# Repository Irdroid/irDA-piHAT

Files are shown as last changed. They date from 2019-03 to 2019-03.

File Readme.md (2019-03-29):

# irDA piHAT Transceiver for Raspberry Pi

The IrDA piHAT is a IrDA SIR transceiver HAT for raspberry Pi. It will allow you to experiment and develop solutions that require IrDA SIR serial communication from 9600 to 115200 baud rates. The IrDA piHAT comes pre-configured for 9600 bps serial SIR communication with the target IR device.

- Complete solution for IrDA communication on Raspberry Pi
- Supports with IrDA® Physical Layer Specification (version 1.3)
- High quality infrared transceiver
- Up to *5 meters IrDA SIR communication
- Supports Baud rates from 9600 – 115200 bps
- No drivers are required

### Version
1.0
### Grab a sample

You can grab a sample board from https://irdroid.eu/product/irda-pihat/

### Todos

 - n/a
 
License
----
GPL 2.0

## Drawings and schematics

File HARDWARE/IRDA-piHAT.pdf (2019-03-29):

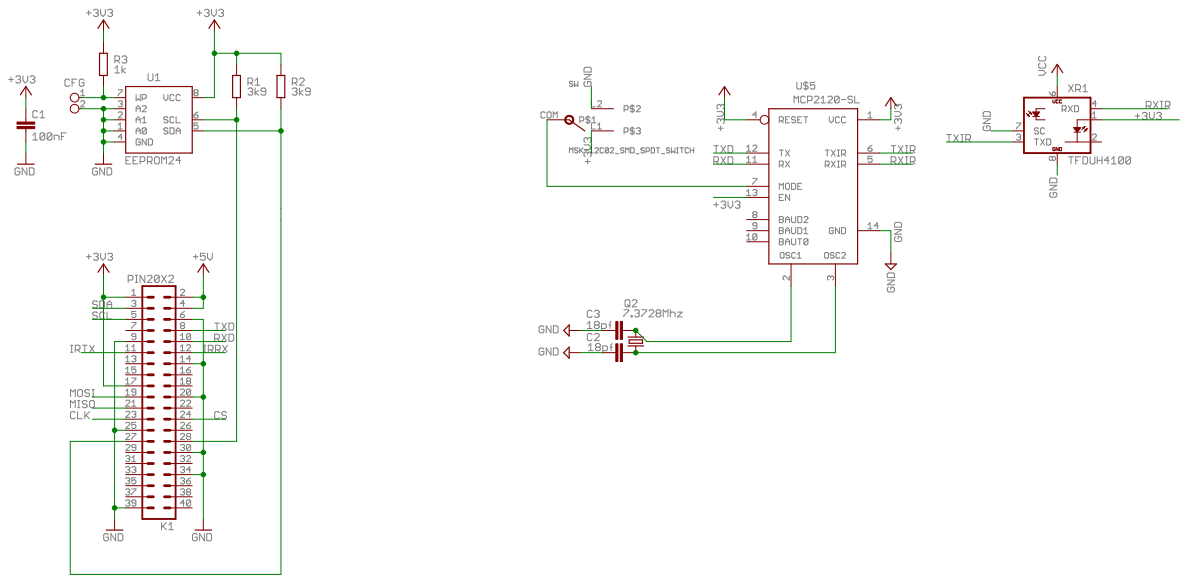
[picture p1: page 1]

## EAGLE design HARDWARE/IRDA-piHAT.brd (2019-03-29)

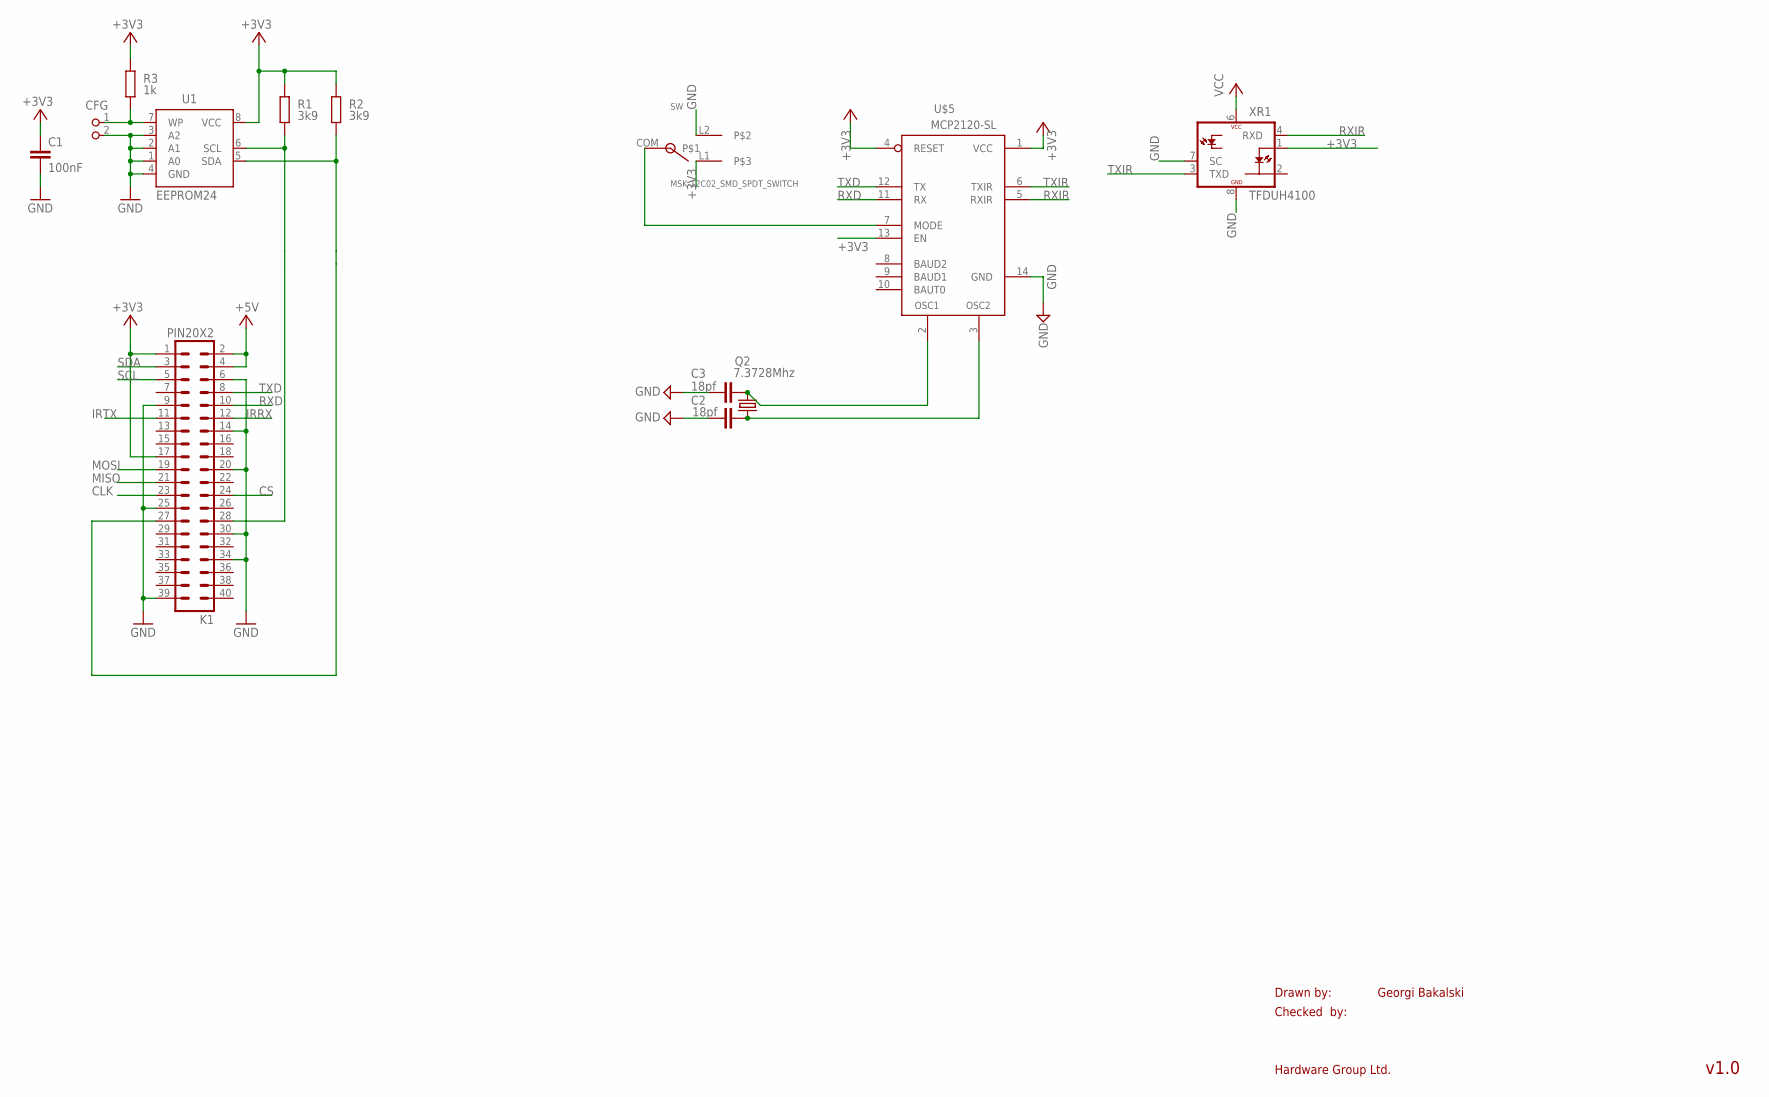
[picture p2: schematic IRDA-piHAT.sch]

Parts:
C1: 100nF; C0805K
C2, C3: 18pf; C603
CFG: PIN2_100; PIN_W_2
K1: PIN20X2; PIN_20X2
Q2: 7.3728Mhz; HC49UP
R1, R2: 3k9; M0805; TOLERANCE 5%
R3: 1k; M0805; TOLERANCE 5%
SW: MSK-12C02_SMD_SPDT_SWITCH; MSK-12C02
U1: EEPROM24; SOIC8
U$5: MCP2120-SL; SO-14
XR1: TFDUH4100; TFDU4-HOR

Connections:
+3V3: C1.1, K1.1, K1.17, R1.2, R2.2, R3.2, SW.L1, U1.8 (VCC), U$5.1 (VCC), U$5.4 (RESET), U$5.13 (EN), XR1.1 (IRED-A), XR1.6 (VCC)
+5V: K1.2, K1.4
CLK: K1.23
CS: K1.24
GND: C1.2, C2.2, C3.2, CFG.2, K1.6, K1.9, K1.14, K1.20, K1.25, K1.30, K1.34, K1.39, SW.L2, U1.1 (A0), U1.2 (A1), U1.3 (A2), U1.4 (GND), U$5.14 (GND), XR1.7 (SC), XR1.8 (GND)
IRRX: K1.12
IRTX: K1.11
MISO: K1.21
MOSI: K1.19
unnamed: CFG.1, R3.1, U1.7 (WP)
unnamed: C3.1, Q2.2, U$5.2 (OSC1)
unnamed: C2.1, Q2.1, U$5.3 (OSC2)
unnamed: SW.COM, U$5.7 (MODE)
unnamed: K1.28, R1.1, U1.6 (SCL)
unnamed: K1.27, R2.1, U1.5 (SDA)
RXD: K1.10, U$5.11 (RX)
RXIR: U$5.5 (RXIR), XR1.4 (RXD)
SCL: K1.5
SDA: K1.3
TXD: K1.8, U$5.12 (TX)
TXIR: U$5.6 (TXIR), XR1.3 (TXD)

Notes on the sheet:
Drawn by:
Checked by:
Hardware Group Ltd.
Georgi Bakalski
v1.0

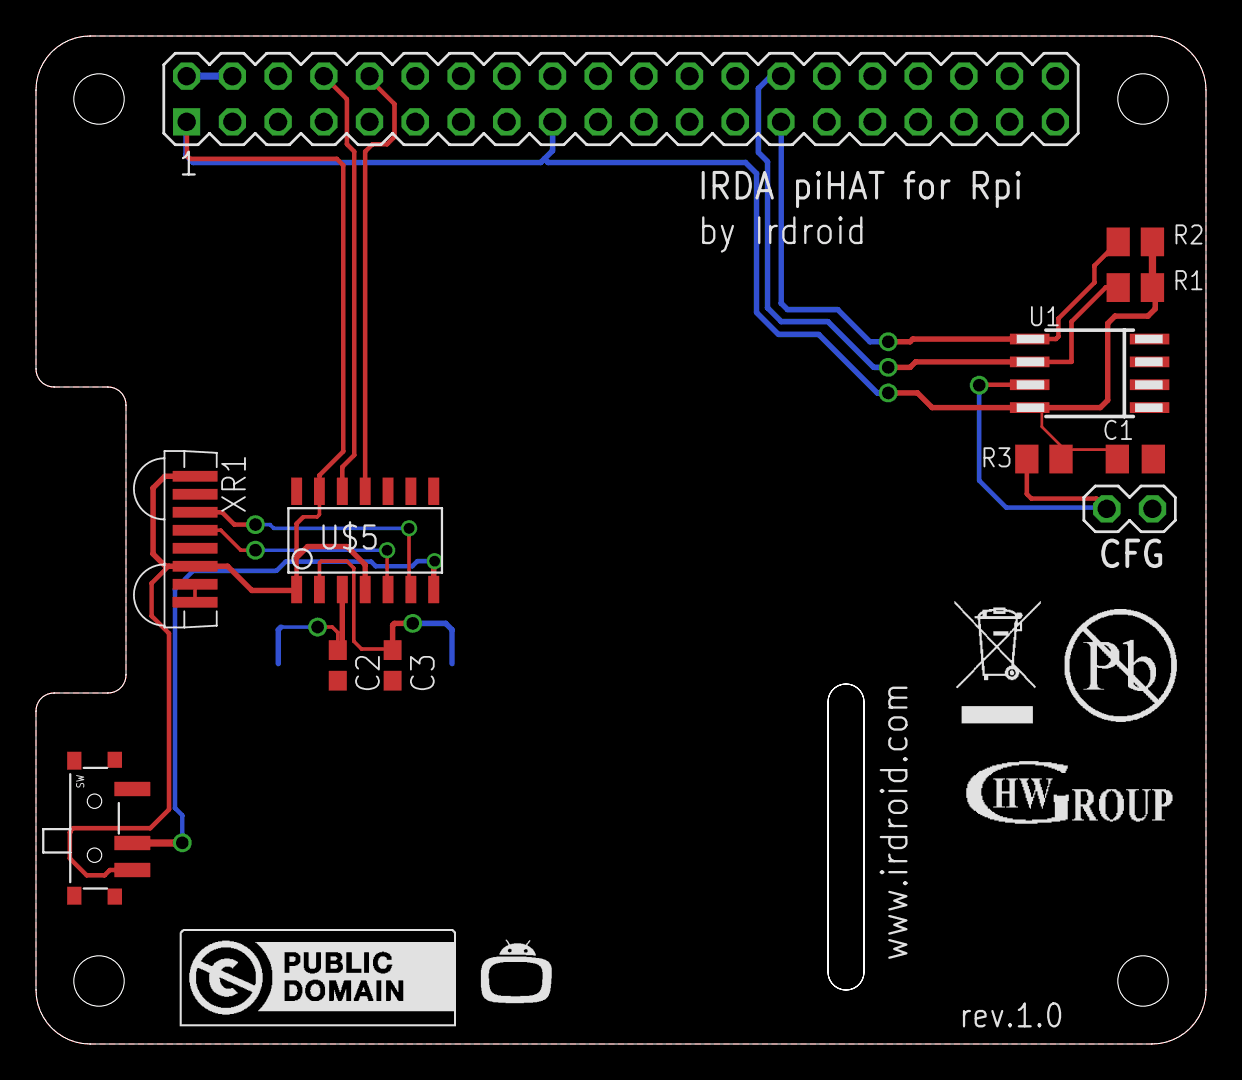
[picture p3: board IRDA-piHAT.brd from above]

Board: 2 copper layers, 65.0 x 56.0 mm, 17 parts (1 on the bottom side), 13 nets.

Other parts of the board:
U$1: LOGO_CC-0
U$2: IRDROIDLOGO
U$3: TRASH
U$4: HWGROUP
